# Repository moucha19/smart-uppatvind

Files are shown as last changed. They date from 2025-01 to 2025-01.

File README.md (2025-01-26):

Smart Uppatvind
===================

## Description

*Redesigned control board for IKEA Uppatvind with smart capabilities.*

The IKEA's air purifiyer lineup is very affordable, and that's especially true for the cheapest Uppatvind. Although it is not the most powerful, it can still improve air quality in a smaller room, while not taking a lot of space. Regardless of the pricepoint, there is not a lot of commercial options, that are this compact.

Unfortunately, it does not come with any smart controls, so I decided to create a replacement board, that should be reliable, relatively easy to make and that also provides some improvements over the original.

## Features

* Part for part replacement of the original - no modifications necessary
* Designed to be integrated into Home Assistent
* Flexible MCU options - both **ESP8684-WROOM-02C** and **ESP32-C3-WROOM-02C** are supported
* Adressable RGB for speed preset and filter life indicators
* Auto-reset circuit to simplify firmware flashing process
* **QWIIC** connector for external sensors
* Optional onboard EEPROM

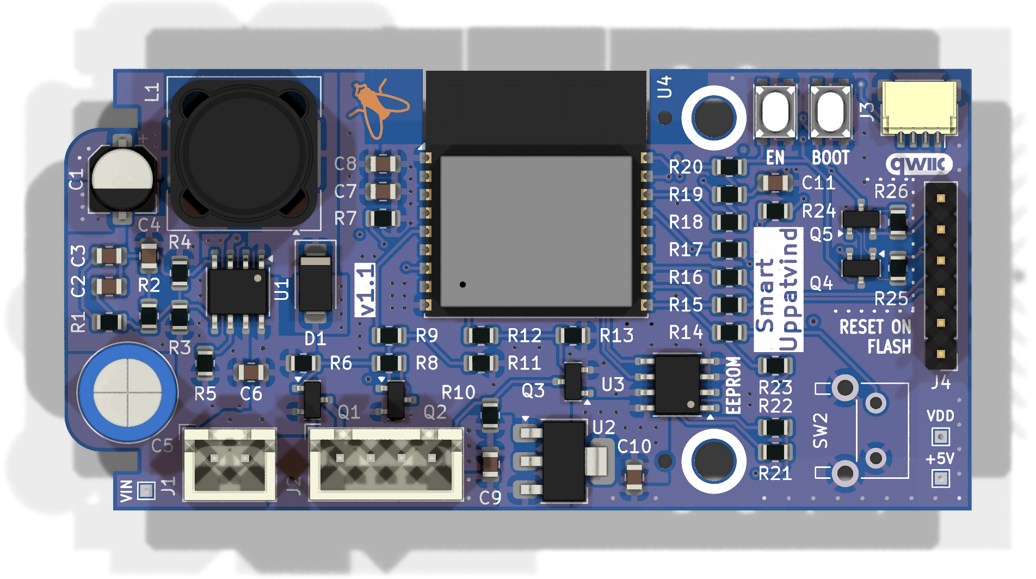
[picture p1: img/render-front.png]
Front PCB view

Comparison with the original

*This project is not affiliated with or endorsed by IKEA. Use this design at your own risk. Ensure you follow proper safety protocols when handling electronic components and soldering.*

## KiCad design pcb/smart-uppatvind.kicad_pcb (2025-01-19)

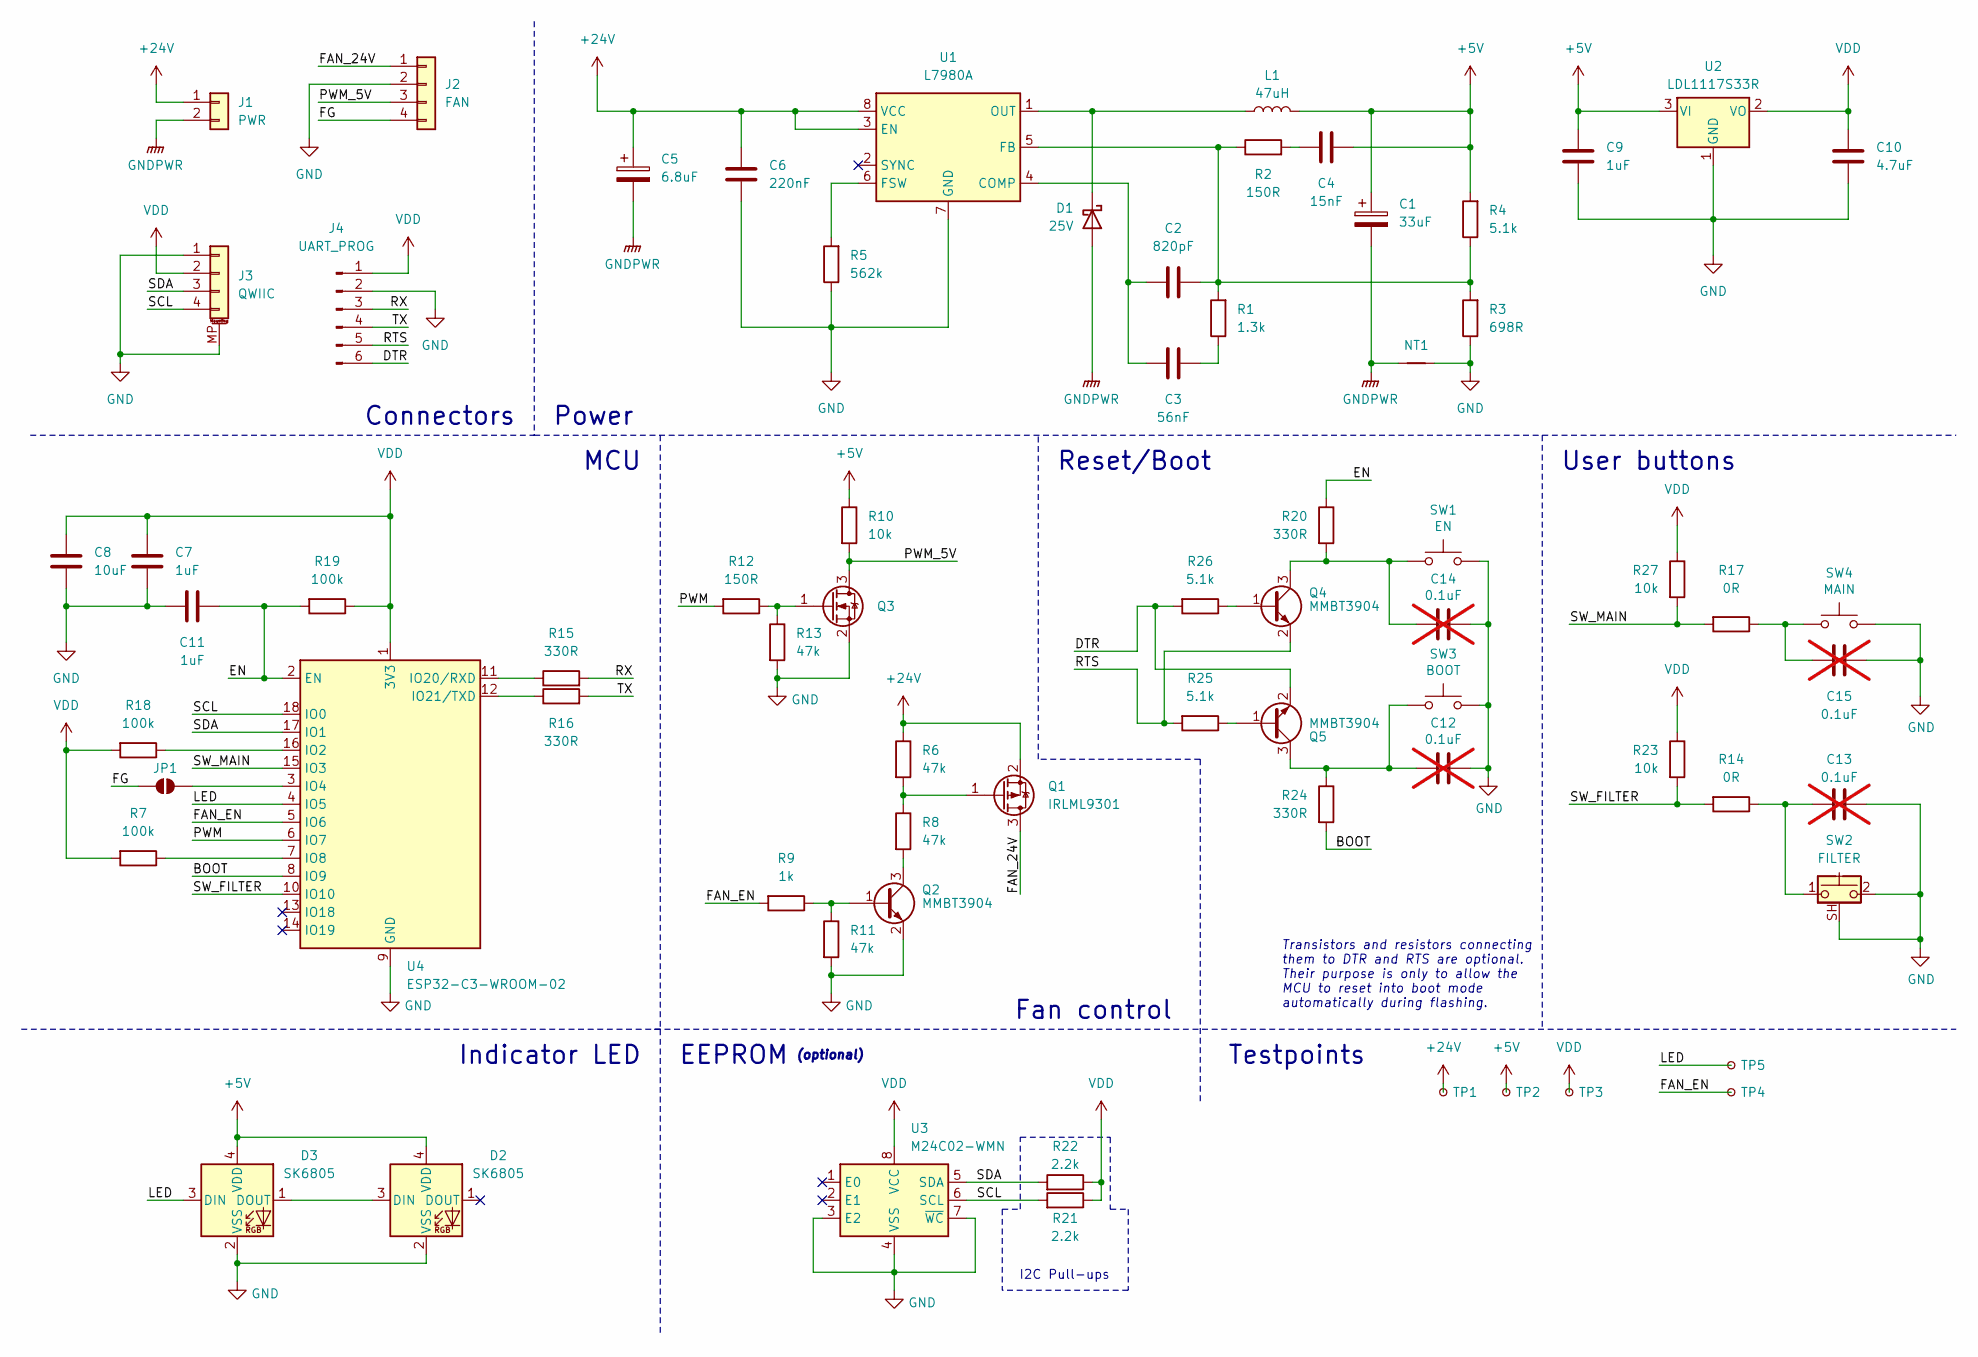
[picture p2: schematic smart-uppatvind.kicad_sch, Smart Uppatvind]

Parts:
C1: 33uF; CP_Elec_5x5.9
C2: 820pF; C_0805_2012Metric
C3: 56nF; C_0805_2012Metric
C4: 15nF; C_0805_2012Metric
C5: 6.8uF; C_Radial_D8.0mm_H7.0mm_P3.50mm
C6: 220nF; C_0805_2012Metric
C7, C9, C11: 1uF; C_0805_2012Metric
C8: 10uF; C_0805_2012Metric
C10: 4.7uF; C_0805_2012Metric
C12, C13, C14, C15: 0.1uF; C_0805_2012Metric; not fitted
D1: 25V; D_SMA
D2, D3: SK6805; LED_SK6805_EC14_1.4x1.4mm
J1: PWR; JST_XH_B2B-XH-A_1x02_P2.50mm_Vertical
J2: FAN; JST_XH_B4B-XH-A_1x04_P2.50mm_Vertical
J3: QWIIC; JST_SH_SM04B-SRSS-TB_1x04-1MP_P1.00mm_Horizontal
J4: UART_PROG; PinHeader_1x06_P2.54mm_Vertical
JP1: SolderJumper_2_Open; SolderJumper-2_P1.3mm_Open_RoundedPad1.0x1.5mm
L1: 47uH; L_Coilcraft_MSS1278H-XXX
NT1: NetTie-2_SMD_Pad2.0mm
Q1: IRLML9301; SOT-23
Q2, Q4, Q5: MMBT3904; SOT-23
Q3: Q_NMOS_GSD; SOT-23
R1: 1.3k; R_0805_2012Metric
R2, R12: 150R; R_0805_2012Metric
R3: 698R; R_0805_2012Metric
R4, R25, R26: 5.1k; R_0805_2012Metric
R5: 562k; R_0805_2012Metric
R6, R8, R11, R13: 47k; R_0805_2012Metric
R7, R18, R19: 100k; R_0805_2012Metric
R9: 1k; R_0805_2012Metric
R10, R23, R27: 10k; R_0805_2012Metric
R14, R17: 0R; R_0805_2012Metric
R15, R16: 330R; R_0805_2012Metric; LCSC C25104
R20, R24: 330R; R_0805_2012Metric
R21, R22: 2.2k; R_0805_2012Metric
SW1: EN; SW_Push_1P1T_Vertical_3x4mm; LCSC C589212
SW2: FILTER; SW_Tactile_G-Switch_GT-TC102B_Angled
SW3: BOOT; SW_Push_1P1T_Vertical_3x4mm; LCSC C589212
SW4: MAIN; SW_Push_K2-6639SP-C4_6x6mm_H5mm
TP1: VIN; TestPoint_THTPad_1.0x1.0mm_Drill0.5mm
TP2: +5V; TestPoint_THTPad_1.0x1.0mm_Drill0.5mm
TP3: VDD; TestPoint_THTPad_1.0x1.0mm_Drill0.5mm
TP4: FAN_EN; TestPoint_Pad_1.0x1.0mm
TP5: LED; TestPoint_Pad_1.0x1.0mm
U1: L7980A; HSOP-8-1EP_3.9x4.9mm_P1.27mm_EP2.3x2.3mm
U2: LDL1117S33R; SOT-223-3_TabPin2
U3: M24C02-WMN; SOIC-8_3.9x4.9mm_P1.27mm
U4: ESP32-C3-WROOM-02; ESP32-CX-WROOM-02

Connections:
+5V: C1.1, C4.2, C9.1, D2.4 (VDD), D3.4 (VDD), L1.2, R4.2, R10.1, TP2.1, U2.3 (VI)
+24V: C5.1, C6.1, J1.1, Q1.2 (S), R6.1, TP1.1, U1.3 (EN), U1.8 (VCC)
/BOOT: R24.2, U4.8 (IO9)
/DTR: J4.6, Q5.2 (E), R26.2
/EN: C11.1, R19.2, R20.1, U4.2 (EN)
/FAN_24V: J2.1, Q1.3 (D)
/FAN_EN: R9.2, TP4.1, U4.5 (IO6)
/FG: J2.4, JP1.1 (A)
/LED: D3.3 (DIN), TP5.1, U4.4 (IO5)
/PWM: R12.2, U4.6 (IO7)
/PWM_5V: J2.3, Q3.3 (D), R10.2
/RTS: J4.5, Q4.2 (E), R25.2
/RX: J4.3, R15.2
/SCL: J3.4, R21.2, U3.6 (SCL), U4.18 (IO0)
/SDA: J3.3, R22.2, U3.5 (SDA), U4.17 (IO1)
/SW_FILTER: R14.2, R23.2, U4.10 (IO10)
/SW_MAIN: R17.2, R27.2, U4.15 (IO3)
/TX: J4.4, R16.2
GND: C6.2, C7.2, C8.2, C9.2, C10.2, C11.2, C12.1, C13.1, C14.1, C15.1, D2.2 (VSS), D3.2 (VSS), J2.2, J3.1, J3.MP (MountPin), J4.2, NT1.2, Q2.2 (E), Q3.2 (S), R3.1, R5.1, R11.2, R13.2, SW1.2, SW2.2, SW2.SH (B), SW3.2, SW4.2, U1.7 (GND), U1.9 (GND), U2.1 (GND), U3.3 (E2), U3.4 (VSS), U3.7 (~WC), U4.9 (GND), U4.19 (GND)
GNDPWR: C1.2, C5.2, D1.2 (A), J1.2, NT1.1
unnamed: C3.2, R1.1
unnamed: C4.1, R2.2
unnamed: C13.2, R14.1, SW2.1
unnamed: C15.2, R17.1, SW4.1
unnamed: D1.1 (K), L1.1, U1.1 (OUT)
unnamed: D2.3 (DIN), D3.1 (DOUT)
unnamed: JP1.2 (B), U4.3 (IO4)
unnamed: Q1.1 (G), R6.2, R8.1
unnamed: Q2.1 (B), R9.1, R11.1
unnamed: Q2.3 (C), R8.2
unnamed: Q3.1 (G), R12.1, R13.1
unnamed: Q4.1 (B), R26.1
unnamed: C14.2, Q4.3 (C), R20.2, SW1.1
unnamed: Q5.1 (B), R25.1
unnamed: C12.2, Q5.3 (C), R24.1, SW3.1
unnamed: C2.1, C3.1, U1.4 (COMP)
unnamed: C2.2, R1.2, R2.1, R3.2, R4.1, U1.5 (FB)
unnamed: R5.2, U1.6 (FSW)
unnamed: R18.1, U4.16 (IO2)
unnamed: R7.1, U4.7 (IO8)
unnamed: R15.1, U4.11 (IO20/RXD)
unnamed: R16.1, U4.12 (IO21/TXD)
VDD: C7.1, C8.1, C10.1, J3.2, J4.1, R7.2, R18.2, R19.1, R21.1, R22.1, R23.1, R27.1, TP3.1, U2.2 (VO), U3.8 (VCC), U4.1 (3V3)

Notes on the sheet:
Connectors
(optional)
Reset/Boot
Testpoints
EEPROM
Power
MCU
Fan control
Transistors and resistors connecting them to DTR and RTS are optional. Their purpose is only to allow the MCU to reset into boot mode automatically during flashing.
I2C Pull-ups
Indicator LED
User buttons

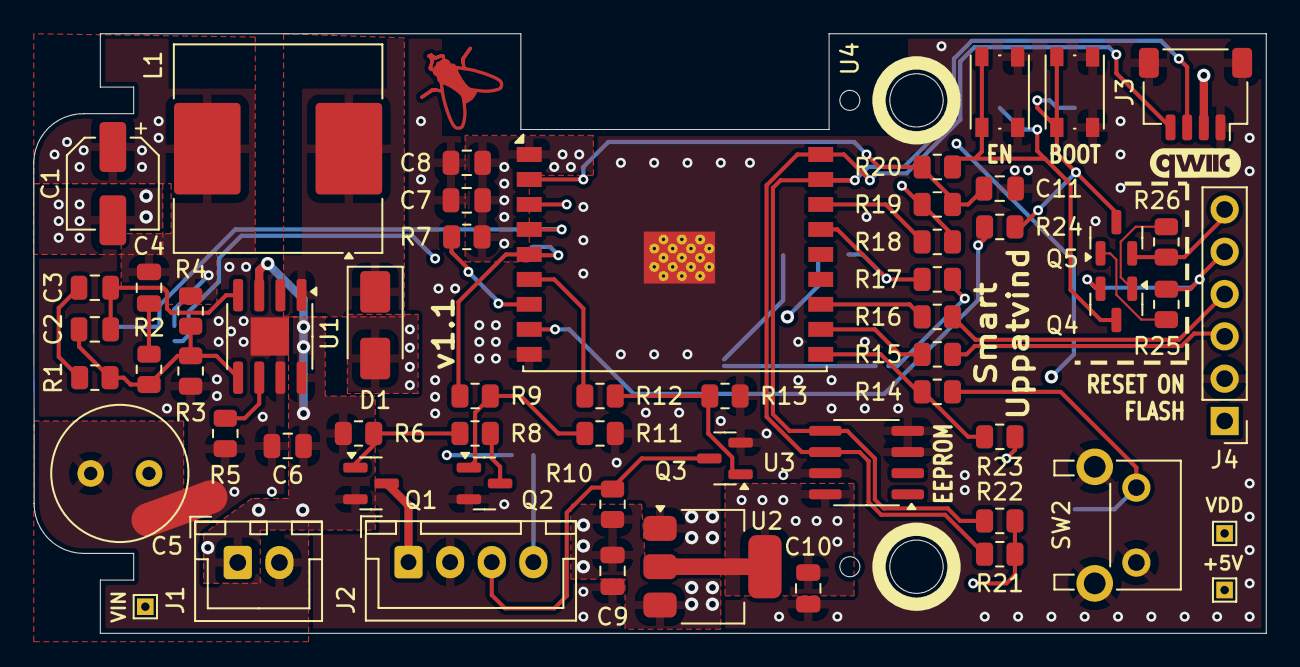
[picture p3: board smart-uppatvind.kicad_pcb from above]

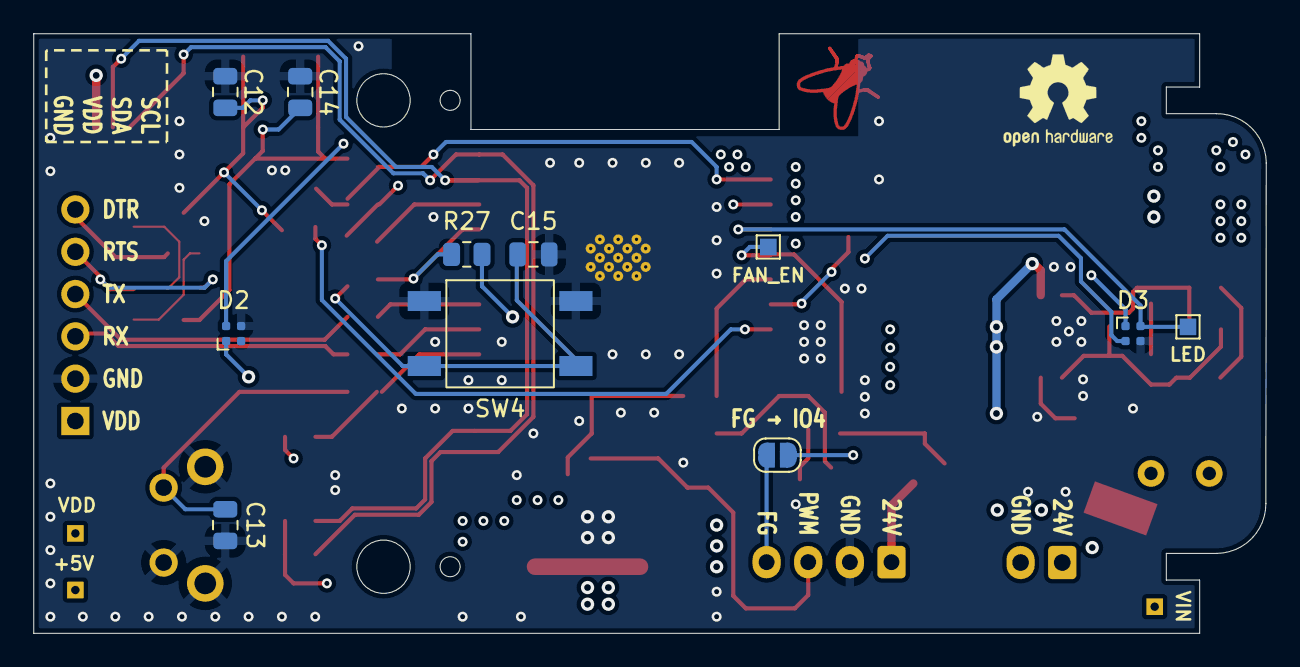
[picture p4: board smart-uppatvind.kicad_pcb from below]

Board: 4 copper layers, 74.0 x 36.0 mm, 70 parts (11 on the bottom side), 43 nets.

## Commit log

2024-07-15 Adjusted layout
    [smart-uppatvind.kicad_pcb]
2024-07-15 Partly routed power management
    [smart-uppatvind.kicad_pcb]
2024-07-16 Adjusted MCU pin assignment, progressed with power routing
    [smart-uppatvind.kicad_pcb, smart-uppatvind.kicad_sch]
2024-07-18 Added logos
    [smart-uppatvind.kicad_pcb]
2024-07-18 Routed all signals, added connector pinout labels
    [smart-uppatvind.kicad_pcb]
2024-07-18 Finishing touches, via stitching
    [smart-uppatvind.kicad_pcb, smart-uppatvind.kicad_sch]
2024-07-19 Minor adjustments, added missing 3D models
    [smart-uppatvind.kicad_pcb, smart-uppatvind.kicad_sch]
2024-07-19 Fixed inverted signals on main connectors, added generated schematic
    [smart-uppatvind.kicad_pcb, smart-uppatvind.kicad_sch]
2024-12-14 Formatted some resistor values
    [smart-uppatvind.kicad_pcb, smart-uppatvind.kicad_sch]
2024-12-14 Improved the schematic readability by grouping it into named segments
    [smart-uppatvind.kicad_sch]
2024-12-15 Fixed incorrect connection of strapping pins for ESP32-C3
    [smart-uppatvind.kicad_pcb, smart-uppatvind.kicad_sch]
2024-12-15 Added back EEPROM text, cleaned up tracks
    [smart-uppatvind.kicad_pcb]
2024-12-15 Connected shield pins of filter switch, made switch pull-ups not optional
    [smart-uppatvind.kicad_pcb, smart-uppatvind.kicad_sch]
2024-12-15 Removed R_Small symbols for consistency
    [smart-uppatvind.kicad_pcb, smart-uppatvind.kicad_sch]
2024-12-15 Unified resistor footprints - removed handsolder variants
    [smart-uppatvind.kicad_pcb, smart-uppatvind.kicad_sch]
2024-12-15 Optimized routing
    [smart-uppatvind.kicad_pcb]
2024-12-29 Added testpoints
    [smart-uppatvind.kicad_pcb, smart-uppatvind.kicad_sch]
2024-12-30 Reannotated components geographically, adjusted designator positions
    [smart-uppatvind.kicad_pcb, smart-uppatvind.kicad_sch]
2025-01-19 Added test point labels to back side, added OSHW symbol
    [smart-uppatvind.kicad_pcb]
2025-01-26 Added board photo and render

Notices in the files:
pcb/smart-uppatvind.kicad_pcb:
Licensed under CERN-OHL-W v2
